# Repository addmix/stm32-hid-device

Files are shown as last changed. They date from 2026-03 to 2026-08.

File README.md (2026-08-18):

# STM32 HID Device
### The "Cybarrghh" is a custom ergonomic STM32 USB HID controller with configurable firmware and desktop configuration software.

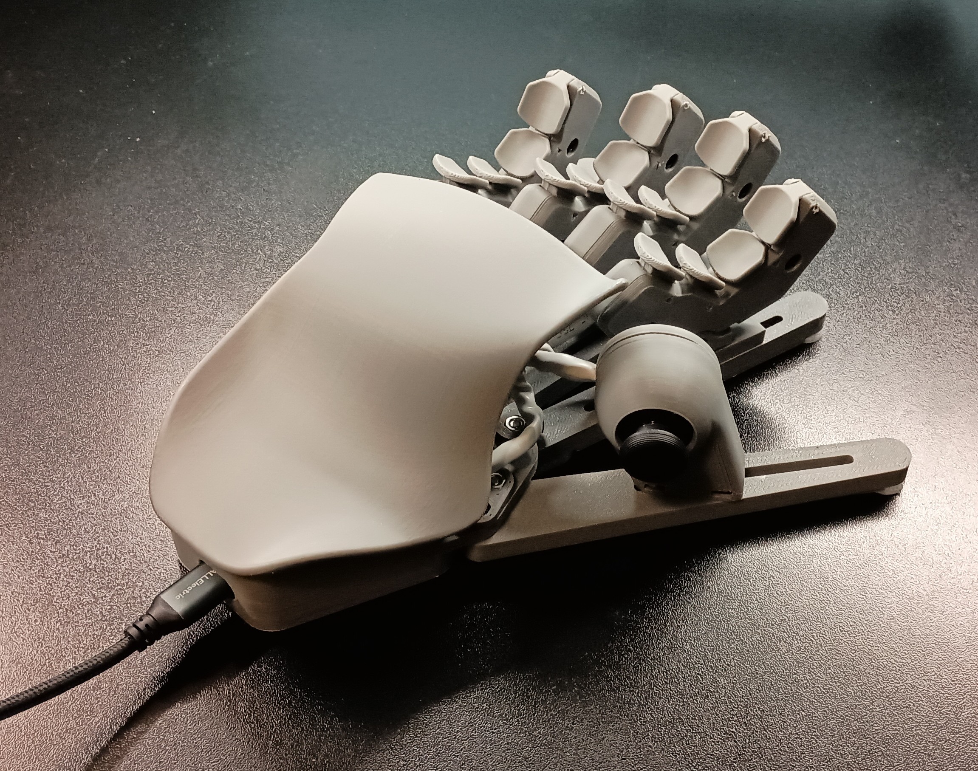
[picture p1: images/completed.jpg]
Image of the completed STM32 device


Reinventing the Gaming Keyboard (https://youtu.be/1f9JZ_KbQRE)   

## Features:
- Custom STM32 firmware
- Desktop configuration app
- USB HID keyboard/mouse/gamepad implementation
- High polling rate (500hz+)
- NKRO keyboard implementation (allows all keys to be pressed simultaneously)
- Ergonomic design
- Short throw switches
- Complete adjustability
- Input remapping, supporting Keyboard, Mouse, and Gamepad input types

## Hardware

#### Materials/supplies used:
- STM32F411CEU6
- Thumbstick module
- PLA filament
- TPU filament
- CYT1073 microswitches
- CAT5E cable
- Hot glue
- Assortment of M3 screws

> For a more detailed materials and cost breakdown, see the [print instructions](/CAD%20files/Print%20instructions.txt)

## Software

#### Prerequisites:
- VSCode
  - PlatformIO extension (it will prompt to install when the project is opened in VSCode)
  - Python (automatically installed with PlatformIO)
- Godot 4.6.2

#### Compiling & Flashing:

- The first time flashing to the STM32, you must hold down the `BOOT0` button while the STM32 powers on (i.e. after resetting) to enter bootloader mode.
  Then, inside VSCode, using the PlatformIO extension, use the "Upload" button in the top right (hotkey Ctrl + Alt + U), which will trigger compilation and upload to the device.

- Subsequent firmware flashes from PlatformIO will automatically enter bootloader mode.
  Manual reset into bootloader mode may still be needed if there are serial communication issues during development

## Development Direction:

My intention for this firmware/software package is that it could be used in any future bespoke input device that I design.

- Improvements to the desktop app UI 
  - Better preset handling
  - Customizable layouts to accomodate different designs
- Improvements to the firmware
  - Performance improvements
  - Microcontroller compatibility (specifically ESP32 boards and Bluetooth)
  - Saving presets to the system ROM
  - Advanced input types and augmentations (macros, counter-strafe helper, etc)

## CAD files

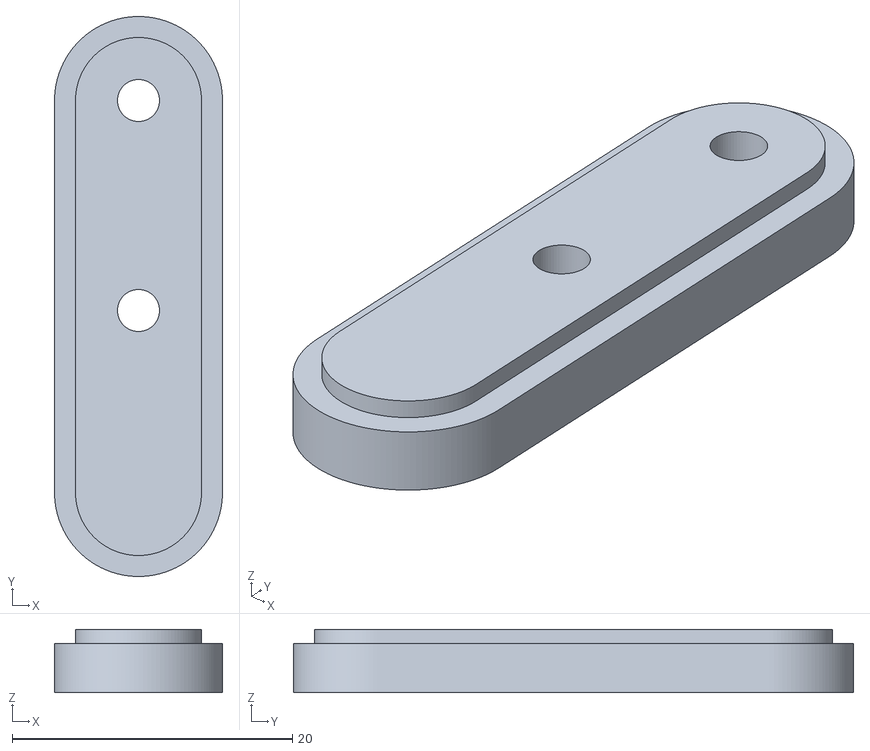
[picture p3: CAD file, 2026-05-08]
CAD files/stl/LargeFoot.stl
12.0 x 40.0 x 4.50

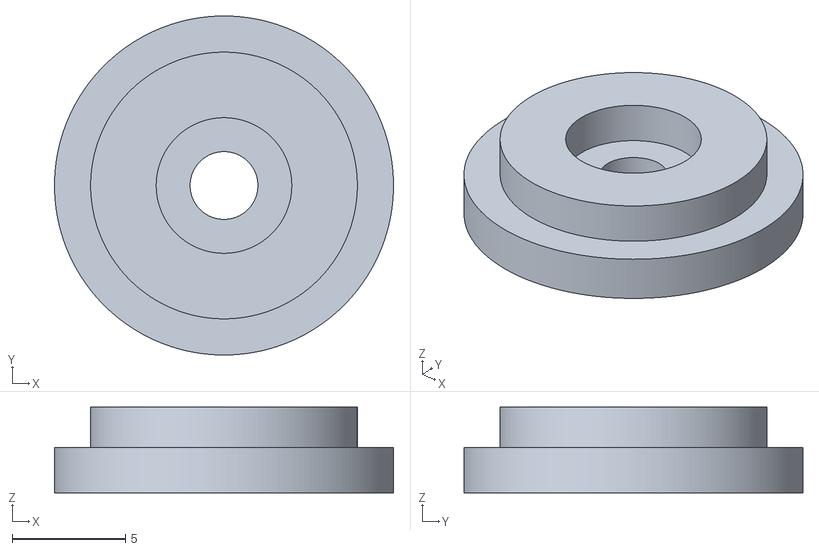
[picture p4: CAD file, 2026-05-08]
CAD files/stl/Foot.stl
15.0 x 15.0 x 3.80

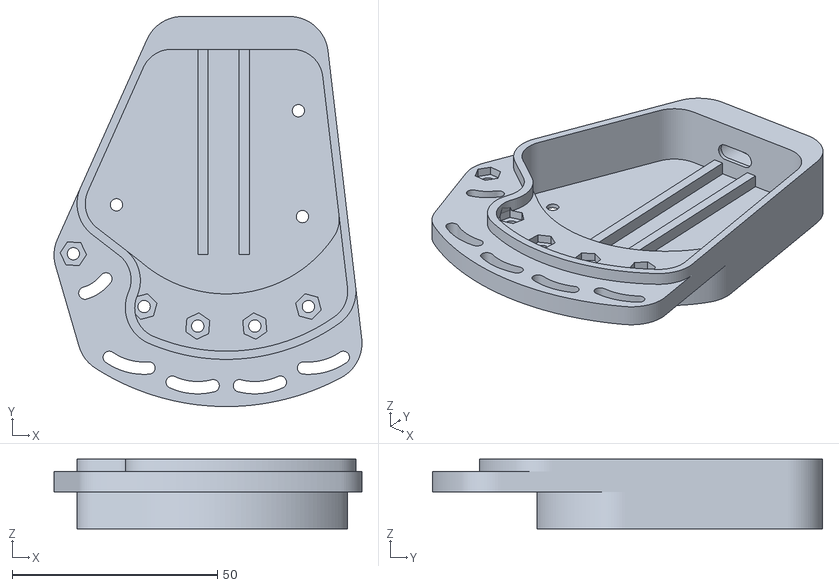
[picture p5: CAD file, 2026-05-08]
CAD files/stl/Base.stl
75.0 x 95.0 x 17.0

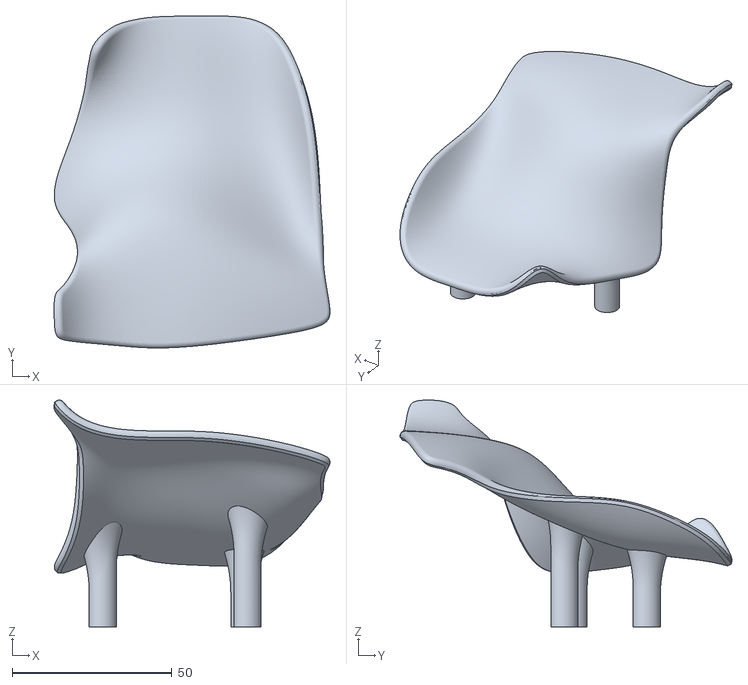
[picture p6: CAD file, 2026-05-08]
CAD files/stl/Handrest.stl
86.4 x 103.8 x 71.0

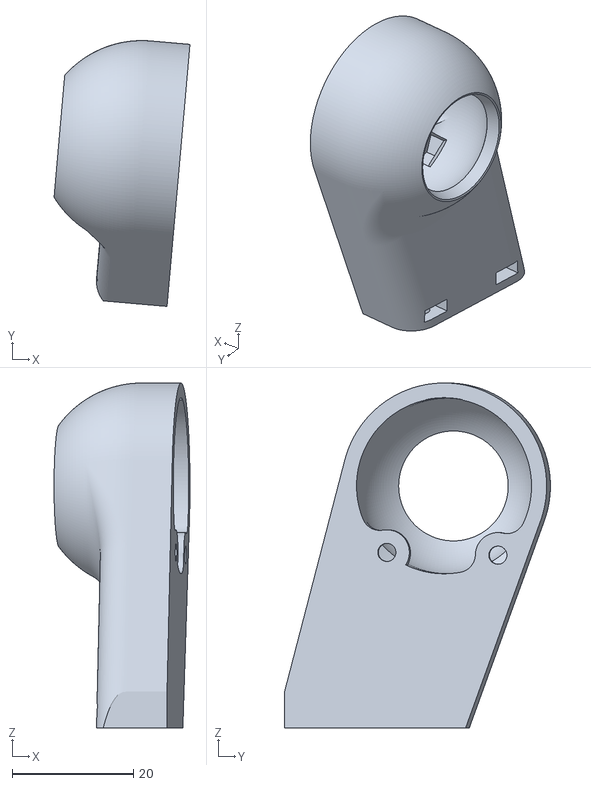
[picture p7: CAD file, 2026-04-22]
CAD files/stl/ThumbMount.stl
22.4 x 43.9 x 57.0

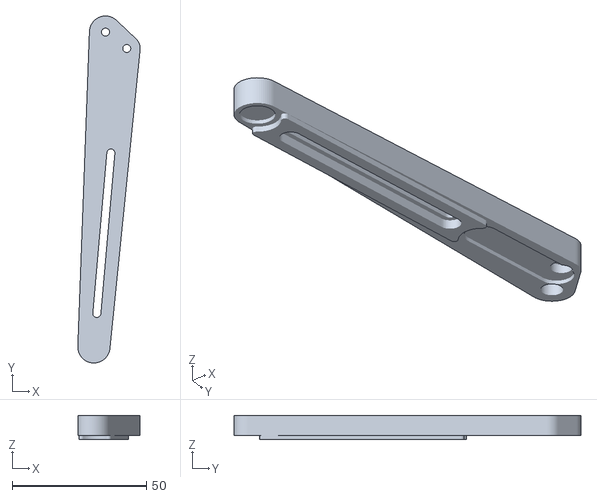
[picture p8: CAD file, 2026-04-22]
CAD files/stl/ThumbRail.stl
23.2 x 129.3 x 9.00

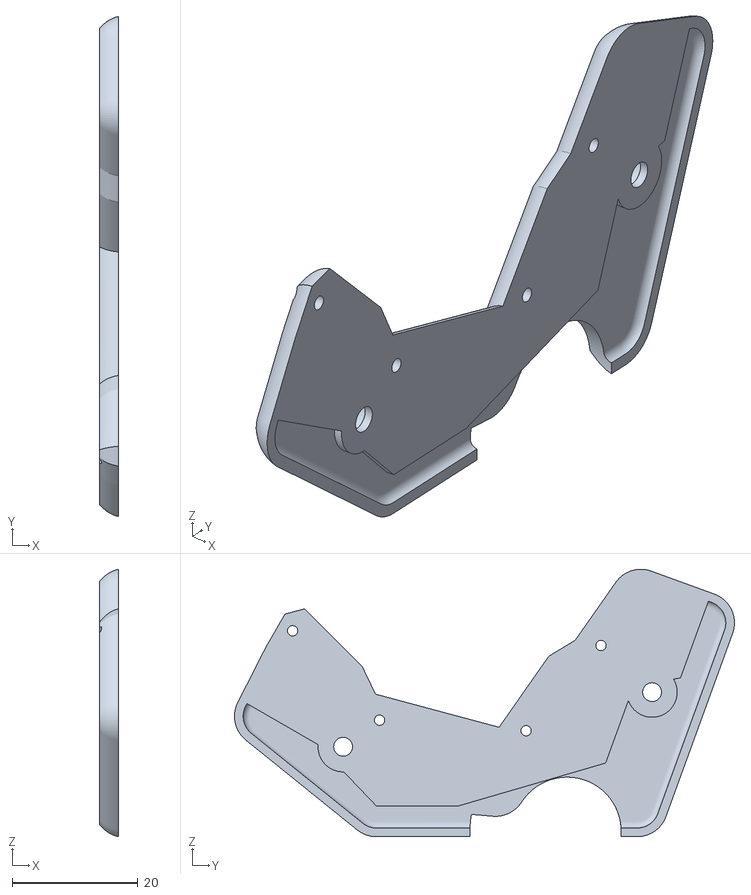
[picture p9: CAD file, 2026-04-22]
CAD files/stl/FingerTowerTop.stl
3.00 x 79.7 x 42.6

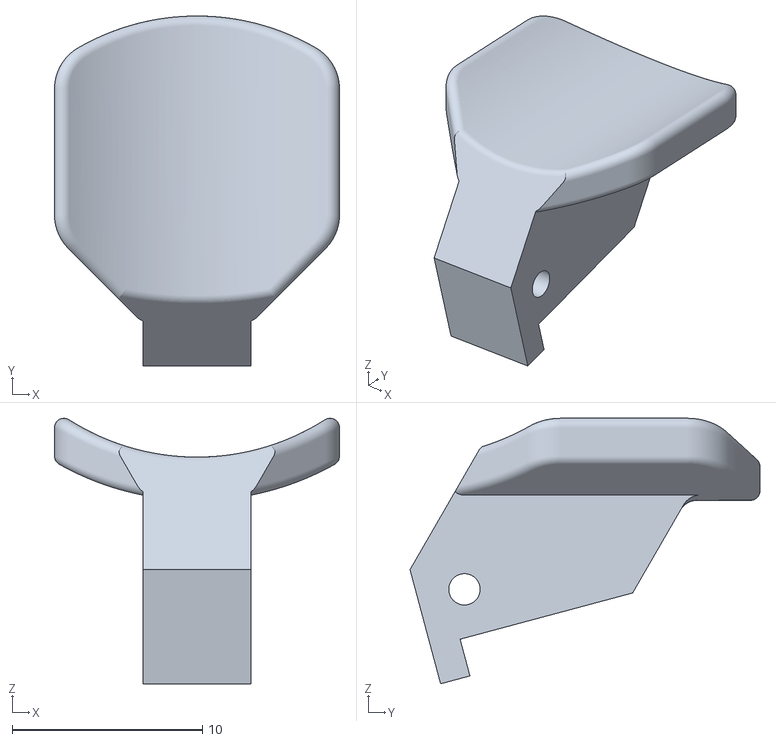
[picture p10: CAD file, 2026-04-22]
CAD files/stl/FingerPaddle (1).stl
15.0 x 18.4 x 14.0

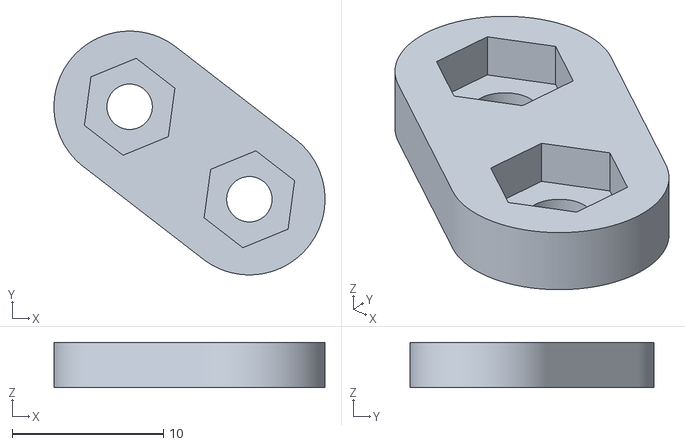
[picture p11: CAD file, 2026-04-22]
CAD files/stl/ThumbNutHolder.stl
17.9 x 16.1 x 3.00

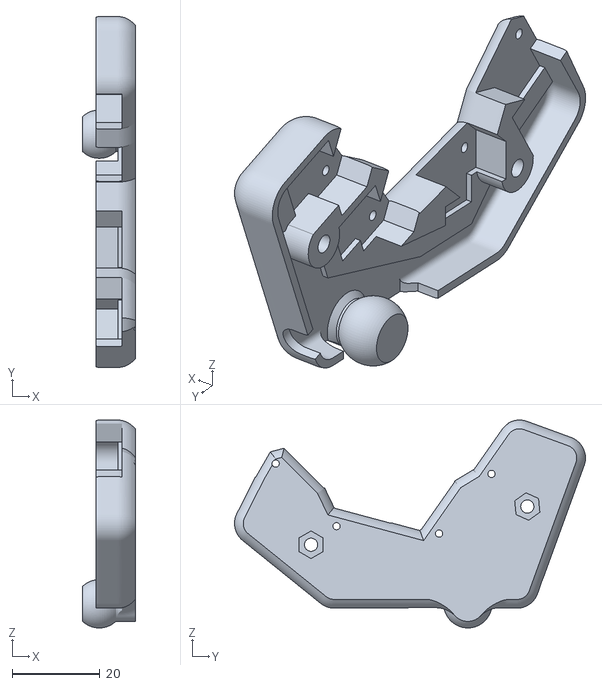
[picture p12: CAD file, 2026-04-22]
CAD files/stl/FingerTowerBottom.stl
12.0 x 79.9 x 47.3

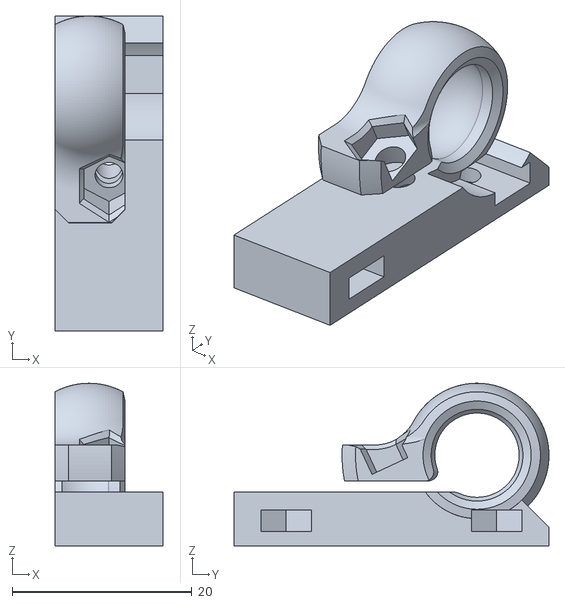
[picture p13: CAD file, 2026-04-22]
CAD files/stl/FingerTowerRingClamp.stl
12.0 x 35.0 x 18.1

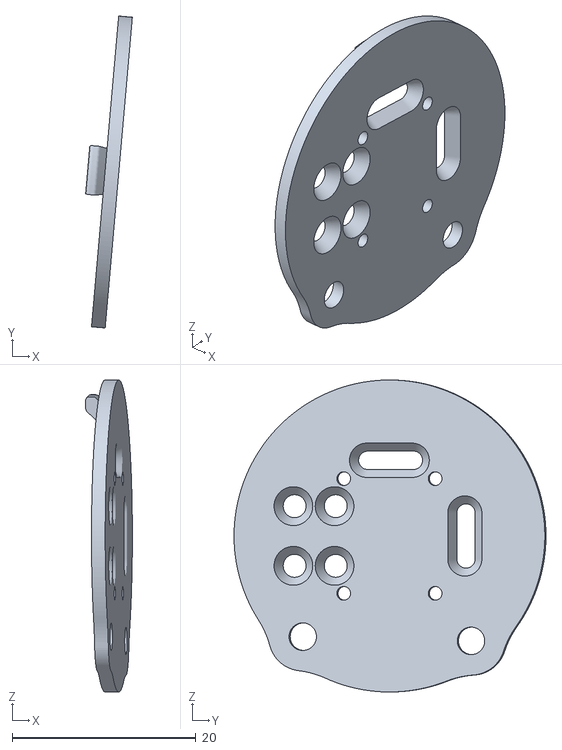
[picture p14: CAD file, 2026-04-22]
CAD files/stl/Body11.stl
5.10 x 34.0 x 34.0

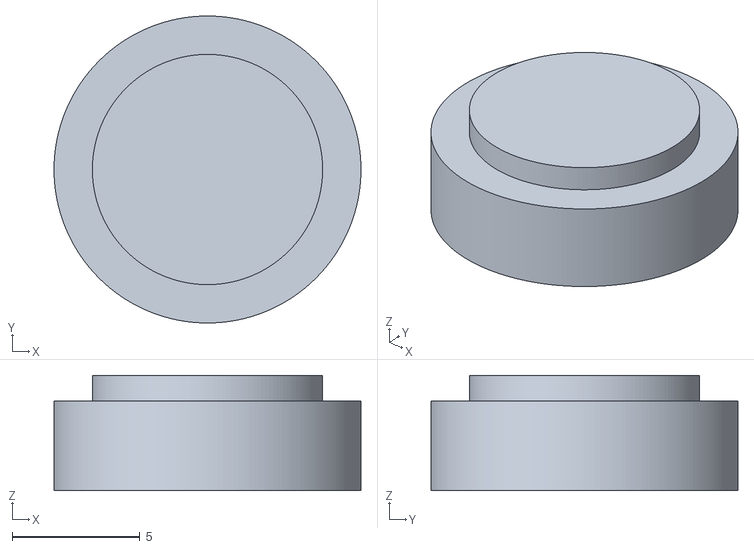
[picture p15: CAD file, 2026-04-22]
CAD files/stl/LittleFoot.stl
12.0 x 12.0 x 4.50

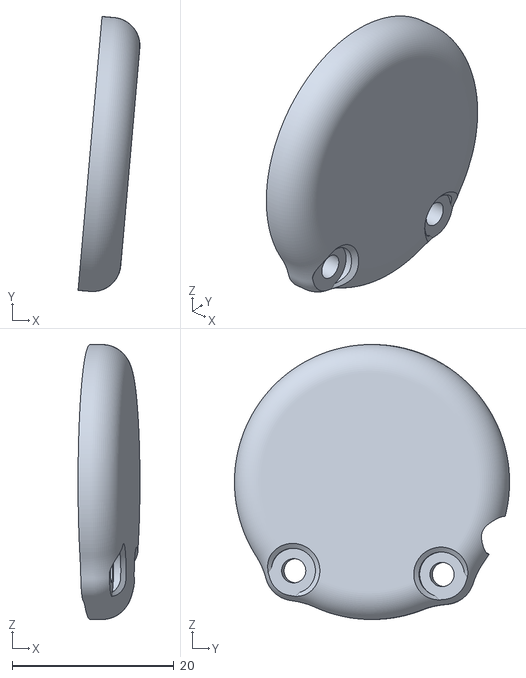
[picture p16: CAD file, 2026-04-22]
CAD files/stl/Backplate.stl
7.65 x 34.0 x 34.0

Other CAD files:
CAD files/stl/NutHolder.stl
CAD files/stl/MountRail.stl
CAD files/stm32 controller.f3d

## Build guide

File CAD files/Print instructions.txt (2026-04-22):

- Base x1 PLA
- Handrest x1 PLA

Thumb (total x1)

- ThumbNutHolder x1 PLA
- ThumbRail x1 PLA
- ThumbMount x1 PLA
- Body11 x1 PLA (or a higher-temperature filament)
- Backplate x1 PLA

- LargeFoot x1 TPU (or other grippy, rubbery filament)
- LittleFoot x1 TPU (or other grippy, rubbery filament)

For each finger (total x4)

- NutHolder x1 (total x4) PLA
- MountRail x1 (total x4) PLA
- FingerTowerRingClamp x1 (total x4) PLA (alternatively PETG, nylon, or other flexible/strong filament)
- FingerTowerBottom x1 (total x4) PLA
- FingerTowerTop x1 (total x4) PLA
- FingerPaddle x4 (total x16) PLA

- LargeFoot x1 (total x4) TPU (or other grippy, rubbery filament)
- LittleFoot x1 (total x4) TPU (or other grippy, rubbery filament)

Combined total for non-3d printed materials

Electronic components:
- STM32F411 x1 - https://www.amazon.com/dp/B0DLNDY4V7 (pack of 2, any stm32 should work, but this is the exact model I used)
- (Optional, but recommended) 2.54mm pitch terminal block 10 pin x5 - https://www.amazon.com/dp/B0BLHJY5NT
- USB-C cable x1
- Ethernet cable ~250mm length x4 - use an old ethernet cable, it's not worth buying a spool of ethernet cable for this project
- CYT1073 microswitch (metal rocker tab not required) x16 - https://www.amazon.com/dp/B088W8WMTB

Screws/fasteners
- Hot glue
- M3x5.7mm heat set insert x3 (total x3) - https://www.amazon.com/dp/B0F5PM83H7
- M3x6mm screws x3
- M3x10mm screw x34
- M3 nut x34
- 1.5mm steel wire (straight), cut to length ~11.5mm x16 - https://www.amazon.com/dp/B09636CL3N

non-3d printed material breakdown:

- Hot glue
- M3x5.7mm heat set insert x3 (total x3) - https://www.amazon.com/dp/B0F5PM83H7
- M3x6mm screws x3 (total x3)
- STM32F411 x1 (total x1) - https://www.amazon.com/dp/B0DLNDY4V7 (pack of 2, any stm32 should work, but this is the exact model I used)
- (Optional, but recommended) 2.54mm pitch terminal block 10 pin x5 (total x5) - https://www.amazon.com/dp/B0BLHJY5NT
- USB-C cable x1 (total x1)

Thumb (total x1)

- M3x10mm screw x6 (total x6)
- M3 nut x6 (total x6)
- Thumbstick module x1 - https://www.amazon.com/dp/B0FPFS5FGT (pack of 2, alternative options available)
- Ethernet cable ~250mm length x1 (total x1) - use an old ethernet cable, it's not worth buying a spool of ethernet cable for this project

For each finger (total x4)

- M3x10mm screw x7 (total x28)
- M3 nut x7 (total x28)
- 1.5mm steel wire (straight), cut to length ~11.5mm x4 (total x16) - https://www.amazon.com/dp/B09636CL3N
- Ethernet cable ~250mm length x1 (total x4) - use an old ethernet cable, it's not worth buying a spool of ethernet cable for this project
- CYT1073 microswitch (metal rocker tab not required) x4 (total x16) - https://www.amazon.com/dp/B088W8WMTB

Total cost, at time of writing to build x2 of this device:
misc filament, less than 1kg, ~$10
STM32F411CEU6 $16
Thumbstick modules $20
CYT1073 microswitches $5
1.5mm steel wire $7
2.54mm pitch terminal blocks (10 pin) $9
M3 screws/insert assortment <$5
Old Ethernet cable - (used) $0

Total cost: $71 / 2 =
$35.5 per device

Helpful assembly tips:
Make sure the holes for the 1.5mm wire are big enough (make sure to print using precise holes/polyholes in your slicer)
You can clean up the holes, and ensure free movement by placing a length of 1.5mm wire in a power drill, and drill through the holes. The finger paddles should spin freely. The two halves of the finger tower should be a friction fit with the 1.5mm wire (you don't want the wire to fall out)

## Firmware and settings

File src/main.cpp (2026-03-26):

#include <Arduino.h>
#include <Adafruit_TinyUSB.h>

#include "pin_declaration.h"
#include "pin_mapping.h"
#include "input_augmentation.h"
#include "nkro_keyboard.h"
#include "input_enums.h"
#include "input_handlers.h"
#include "serialization.h"
#include "config.h"

const uint8_t desc_hid_report[] = {
  TUD_HID_REPORT_DESC_NKRO_KEYBOARD (HID_REPORT_ID(KEYBOARD)),
  TUD_HID_REPORT_DESC_MOUSE         (HID_REPORT_ID(MOUSE)),
  TUD_HID_REPORT_DESC_GAMEPAD       (HID_REPORT_ID(GAMEPAD)),
  //TUD_HID_REPORT_DESC_CONSUMER      (HID_REPORT_ID(CONSUMER_CONTROL)),
};

Adafruit_USBD_CDC usb_serial; //the adafruit tinyusb serial object must be used to retain both HID and serial communication
Adafruit_USBD_HID usb_hid;

void setup() {
  usb_serial.begin(115200);
  usb_serial.setTimeout(2000); //timeout after 0.1 seconds
  //delay(50);
  
  //HID setup  
  usb_hid.setPollInterval(2);
  usb_hid.setReportDescriptor(desc_hid_report, sizeof(desc_hid_report));
  usb_hid.begin();
  
  //setup pins for pullup/pulldown
  for (const auto& [key, pin] : pin_map) {
    if (pin.analog) {
      pinMode(pin.pin_name, INPUT_ANALOG);
      continue;
    }
    if (pin.inactive_value == LOW) pinMode(pin.pin_name, INPUT_PULLDOWN);
    else pinMode(pin.pin_name, INPUT_PULLUP);
  }

  while (!TinyUSBDevice.mounted()) delay(100);
}

bool nkro_updated = false;
hid_mouse_report_t last_mouse = mouse;
hid_gamepad_report_t last_gamepad = gamepad;
void loop() {
  if (not usb_hid.ready()) {
    //Serial.println("not ready");
    delayMicroseconds(100);
    return;
  }
  //delay(50);
  //run parsing routine
  parse_serial();


  //TODO
  //TODO Change this to a queue/buffer based implementation
  //TODO

  //update all pin readings as concurrently as possible
  for (auto& [key, pin] : pin_map) {
    pin.update();
  }

  //apply input augmentations
  for (auto& augment : augmentations) {
    augment.apply_augmentations();
  }

  for (auto& binding : pin_bindings) {
    binding.update_value();
  }


  //reset mouse inputs
  memset(&mouse, 0, sizeof(mouse));
  
  //reset gamepad inputs
  memset(&gamepad, 0, sizeof(gamepad));
  gamepad.hat = GAMEPAD_HAT_CENTERED;

  for (PinMapping &pin_binding : pin_bindings) {
    switch (pin_binding.input_type) {
      case KEYBOARD:
        //TODO remove this "nkro_updated" logic, and just check if the report is different at the end of the iteration
        nkro_updated = handleKeyboardNKRO(pin_binding) or nkro_updated; //this ordering is necessary to prevent nkro_updated from short-circuiting and preventing the function call
        break;
      case MOUSE:
      //TODO: Simplify this to be more like the gamepad axis handler
        mouse.buttons |= handleMouseButtons(pin_binding);
        mouse.x += handleMouseMovementX(pin_binding);
        mouse.y += handleMouseMovementY(pin_binding);
        mouse.wheel += handleMouseScroll(pin_binding);
        mouse.pan += handleMousePan(pin_binding);
        break;
      case GAMEPAD_BUTTON:
      //TODO: Simplify this to be more like the gamepad axis handler
        gamepad.buttons |= handleGamepadButtons(pin_binding);
        break;
      case GAMEPAD_HAT:
      //TODO: Simplify this to be more like the gamepad axis handler
        gamepad.hat = handleGamepadHat(pin_binding);
        break;
      case GAMEPAD_AXIS:
        handleGamepadAxis(pin_binding); //I think this might be a better convention than the previous ones. It will be easier to separate out into multiple files if needed
        break;
      //case RID_CONSUMER_CONTROL:
        //usb_hid.sendReport16(RID_CONSUMER_CONTROL, HID_USAGE_CONSUMER_VOLUME_DECREMENT);
    }
  }

  if (nkro_updated) {
    if (!usb_hid.ready()) return; //stop-gap fix for multiple reports not being allowed in each usb_hid poll
    //TODO fix the reporting logic for this
    NKROReport(usb_hid, KEYBOARD);
    nkro_updated = false;
    Serial.println("send nkro");
  }
  if (
    gamepad.buttons != last_gamepad.buttons or
    gamepad.hat != last_gamepad.hat or
    gamepad.x  != last_gamepad.x  or
    gamepad.y  != last_gamepad.y  or
    gamepad.z  != last_gamepad.z  or
    gamepad.rz != last_gamepad.rz or
    gamepad.rx != last_gamepad.rx or
    gamepad.ry != last_gamepad.ry
  ) {
    if (!usb_hid.ready()) return; //stop-gap fix for multiple reports not being allowed in each usb_hid poll
    usb_hid.sendReport(GAMEPAD, &gamepad, sizeof(gamepad));
    last_gamepad = gamepad;
    Serial.println("send gamepad");
    //Serial.println(gamepad.x);
    //Serial.println(last_gamepad.x);
  }
  if (
    mouse.buttons != last_mouse.buttons or
    mouse.x != 0.0 or
    mouse.y != 0.0 or
    mouse.wheel != 0.0 or
    mouse.pan != 0.0
  ) {
    if (!usb_hid.ready()) return; //stop-gap fix for multiple reports not being allowed in each usb_hid poll
    usb_hid.sendReport(MOUSE, &mouse, sizeof(mouse));
    last_mouse = mouse;
    Serial.println("send mouse");
  }

  //we don't need to run at full speed. My measurement showed that iterations take ~43 microseconds. This could possible help avoid USB buffer issues, though idk if that's even a problem
  delayMicroseconds(457);
  
}









//ideal structure

//fast clock interrupt timer samples pins, if a pin has changed, add it to a queue
//do debounce logic here ^^

//allegedly, this is a fast way to sample pins:
//uint32_t new_state = GPIOx->IDR;
//changed = new_state ^ previous_state

//slower loop()/polling function then processes the state change queue, and calls out to a function pointer 
//to handle that specific pin (depending on config, if it's keyboard/mouse/gamepad or analog/digital)

//these pointer'd functions can only modify the current state (i.e. nkro report, gamepad report)

//at the end of the iteration, reports that have been changed will be reported to usbhid












//This is an example of an interrupt scanning
/*
#include <Arduino.h>

/* -----------------------------
   Shared state between ISR/loop
----------------------------- 

volatile bool scan_flag = false;   // set by ISR when scan should run

/* -----------------------------
   Timer ISR
-----------------------------

HardwareTimer *scanTimer = nullptr;

void scanISR() {
    scan_flag = true;   // signal main loop
}

/* -----------------------------
   Timer setup
----------------------------- 

void setupScanTimer(uint32_t frequency_hz)
{
    scanTimer = new HardwareTimer(TIM2);   // choose an available timer

    scanTimer->setOverflow(frequency_hz, HERTZ_FORMAT);  // e.g. 1000 Hz
    scanTimer->attachInterrupt(scanISR);
    scanTimer->resume();
}

/* -----------------------------
   Setup
-----------------------------

void setup() {
    Serial.begin(115200);

    setupScanTimer(1000);   // 1 kHz scan rate
}

/* -----------------------------
   Input scan (runs in loop)
-----------------------------

void scanInputs() {
    // this will eventually contain:
    // pin_bindingsping.update_value()
}

/* -----------------------------
   Main loop
-----------------------------

void loop() {

    if (scan_flag) {
        scan_flag = false;

        scanInputs();   // run input scan
    }

    // slower tasks go here
}
*/

//reset from code: NVIC_SystemReset();

//Serial.readString()

//HAL_FLASH_Unlock()
//HAL_FLASH_Program()
//HAL_FLASH_Erase()

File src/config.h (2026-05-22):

#pragma once
#include "pin_declaration.h"
#include "pin_mapping.h"
#include "input_augmentation.h"
#include "input_enums.h"

//TODO replace with std::vector. reserve() and resize()
//Maybe this could be fixed by mapping pins to unique identifier names, like thumb_x or index_tip
std::map<uint, Pin> pin_map = {
  { PA_0, Pin(PA_0, true) },
  { PA_1, Pin(PA_1, true) },
  { PA_2, Pin(PA_2) },
  { PB_9, Pin(PB_9) },
  { PB_8, Pin(PB_8) },
  { PB_7, Pin(PB_7) },
  { PB_6, Pin(PB_6) },
  { PB_5, Pin(PB_5) },
  { PB_4, Pin(PB_4) },
  { PB_3, Pin(PB_3) },
  { PA_15, Pin(PA_15) },
  { PA_10, Pin(PA_10) },
  { PA_9, Pin(PA_9) },
  { PA_8, Pin(PA_8) },
  { PB_10, Pin(PB_10) },
  { PB_1, Pin(PB_1) },
  { PB_0, Pin(PB_0) },
  { PA_7, Pin(PA_7) },
  { PA_6, Pin(PA_6) },
};

//eh, low priority, as I think that typically Macros are abused to get an unfair advantage instead of being useful toons 99% of the time
//anyways, normal hotkeys can be done by binding multiple keys to a single pin
//Consider different config structures for input mappings, to accommodate things like macros
std::vector<PinMapping> pin_bindings = {
    //thumb
    PinMapping(PA_2, KEYBOARD, HID_KEY_CONTROL_LEFT),  //click
    PinMapping(PA_2, KEYBOARD, HID_KEY_ALT_LEFT),  //click
    PinMapping(PA_2, KEYBOARD, HID_KEY_M),  //click
    
    //thumbstick
    PinMapping(PA_1, KEYBOARD, HID_KEY_D, true),
    PinMapping(PA_0, KEYBOARD, HID_KEY_W, true),
    PinMapping(PA_1, KEYBOARD, HID_KEY_A, false),  //y (+3.3v up)
    PinMapping(PA_0, KEYBOARD, HID_KEY_S, false),  //x (+3.3v forward)
    
    PinMapping(PA_1, GAMEPAD_AXIS, GAMEPAD_LEFT_STICK_X, false),
    PinMapping(PA_0, GAMEPAD_AXIS, GAMEPAD_LEFT_STICK_Y, true),
    
    //index
    PinMapping(PB_9, KEYBOARD, HID_KEY_1),  //tip
    PinMapping(PB_8, KEYBOARD, HID_KEY_R), //rest
    PinMapping(PB_7, KEYBOARD, HID_KEY_NONE),  //inner
    PinMapping(PB_6, KEYBOARD, HID_KEY_NONE),  //pad
    
    //middle
    PinMapping(PB_5, KEYBOARD, HID_KEY_5), //tip
    PinMapping(PB_4, KEYBOARD, HID_KEY_NONE),  //rest
    PinMapping(PB_3, KEYBOARD, HID_KEY_B),  //inner
    PinMapping(PA_15, KEYBOARD, HID_KEY_NONE),  //pad
    
    //ring
    PinMapping(PA_10, KEYBOARD, HID_KEY_E),  //tip
    PinMapping(PA_9, KEYBOARD, HID_KEY_NONE),  //rest
    PinMapping(PA_8, KEYBOARD, HID_KEY_NONE),  //inner
    PinMapping(PB_10, KEYBOARD, HID_KEY_NONE), //pad
    
    //pinky
    PinMapping(PB_1, KEYBOARD, HID_KEY_G), //tip
    PinMapping(PB_0, KEYBOARD, HID_KEY_SPACE), //rest
    PinMapping(PA_7, KEYBOARD, HID_KEY_SHIFT_LEFT), //inner
    PinMapping(PA_6, KEYBOARD, HID_KEY_CONTROL_LEFT),  //pad
};

std::vector<InputAugmentation> augmentations = {
  InputAugmentation::rotation(PA_0, PA_1, ROTATION, radians(15.0f)),
  InputAugmentation::rotation(PA_1, PA_0, ROTATION, radians(15.0f)),
};

//TODO remove these duplicate defines
#define START_CODE_BYTE_SIZE 2
#define SECTION_HEADER_BYTE_SIZE 3
//2 bytes for start code, 2 bytes for payload length, >=1 byte for payload, and 1 byte for checksum
#define MINIMUM_MESSAGE_LENGTH START_CODE_BYTE_SIZE + SECTION_HEADER_BYTE_SIZE //this also represents the formatting data of commands, which excludes the payload


u_int16_t get_pin_data_size(u_int8_t index = 255);
u_int16_t get_mapping_data_size(u_int8_t index = 255);
u_int16_t get_augment_data_size(u_int8_t index = 255);

u_int16_t get_config_data_size() {
  return get_pin_data_size() + SECTION_HEADER_BYTE_SIZE + get_mapping_data_size() + SECTION_HEADER_BYTE_SIZE + get_augment_data_size() + SECTION_HEADER_BYTE_SIZE;
}

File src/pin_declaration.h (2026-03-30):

#pragma once
#include <map>
#include <Arduino.h>
#define ADC_MAX_VALUE 1024
#define DEBOUNCE_TICKS_MS 15

#define PIN_BYTE_SIZE 4U //pin number, analog, inactive value, inactive value
struct Pin {
    static const u_int8_t BYTE_SIZE = PIN_BYTE_SIZE;
    PinName pin_name = NC;
    bool analog = false;
    u_int16_t inactive_value = HIGH;
    int value = 0;
    u_int last_change_time = -DEBOUNCE_TICKS_MS;
    int center = ADC_MAX_VALUE / 2; 
    //int range = ADC_MAX_VALUE / 2;
    
    Pin() = default;
    Pin(PinName pin_name, bool analog = false, int inactive_value = HIGH) : pin_name(pin_name), analog(analog), inactive_value(inactive_value) {};

    void update() {
        if (is_bounce() and not analog) return;
        int new_value = 0;
        if (analog) new_value = analogRead(pin_name) - center;
        else new_value = digitalRead(pin_name);

        if (value != new_value) {
            last_change_time = millis();

            //if (not analog) Serial.println("value changed " + (String) value + (String) new_value);
        }

        value = new_value;
    }
    const bool is_bounce() {
        return (millis() - last_change_time) <= DEBOUNCE_TICKS_MS;
    }

    void print() {
        Serial.println(
            "pin number=" + (String) pin_name + 
            " analog=" + (String) analog +
            " inactive value=" + (String) inactive_value
        );
    }
    
    void to_bytes(u_int8_t *&return_buffer) const {
        *return_buffer++ = pin_name;
        *return_buffer++ = analog;
        *return_buffer++ = inactive_value >> 8 & 0xFF;
        *return_buffer++ = inactive_value & 0xFF;
    }

    static Pin from_bytes(u_int8_t *&read_buffer) {//static func from_bytes(bytes : PackedByteArray) -> PinDeclaration:
        //if bytes.size() != BYTE_SIZE:
        //	push_error("Passed byte array does not match the byte size of PinDeclaration.")
        
        PinName pin_name = (PinName) *read_buffer++;//var _pin_name : int = bytes[0]
        bool analog = *read_buffer++;//var _analog : bool = bytes[1]
        u_int16_t inactive_value = ((u_int16_t) *read_buffer++ << 8 ) + (u_int16_t) *read_buffer++;//var _inactive_value : int = (bytes[2] << 8) + bytes[3]
        
        return Pin(pin_name, analog, inactive_value);//return PinDeclaration.new(_pin_name, _analog, _inactive_value)
    }

    static void from_byte_array(u_int8_t *&read_buffer, Pin *&return_buffer, u_int16_t items_to_parse) {//static func from_byte_array(bytes : PackedByteArray) -> Array[PinDeclaration]:
        for (size_t i = 0; i < items_to_parse; ++i) {
            *return_buffer++ = from_bytes(read_buffer);
        }
    }
};

extern std::map<uint, Pin> pin_map;

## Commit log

2026-03-17 Initial work on desktop app
    [plugin.cfg]
2026-03-19 Fixed issue with key chords/hotkeys
    [main.cpp, pin_declaration.h]
2026-03-26 Various fixes and improvements
    [config.h, main.cpp, pin_declaration.h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]
2026-03-27 Desktop app can now fully parse device configs
2026-03-29 Implemented device-side parsing of byte configs
2026-04-13 Prevent serial buffer from overflowing on large commands
    [serialization.h]
2026-04-22 Add CAD files under CC BY-NC-SA license
    [Backplate.stl, Base.stl, Body11.stl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]
2026-04-28 Fix issue when parsing config
    [serialization.h]
2026-05-08 Added option to fill UI with config from device
2026-05-08 Ergonomics iteration
    [Base.stl, Foot.stl, Handrest.stl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]
